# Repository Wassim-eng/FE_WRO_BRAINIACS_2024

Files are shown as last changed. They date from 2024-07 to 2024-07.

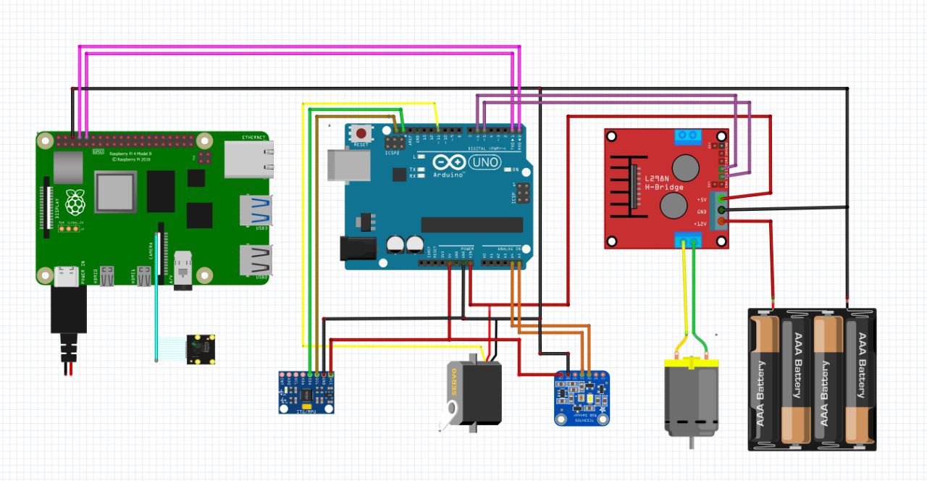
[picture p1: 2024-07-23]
schemes/Schematic_Diagram.jpeg

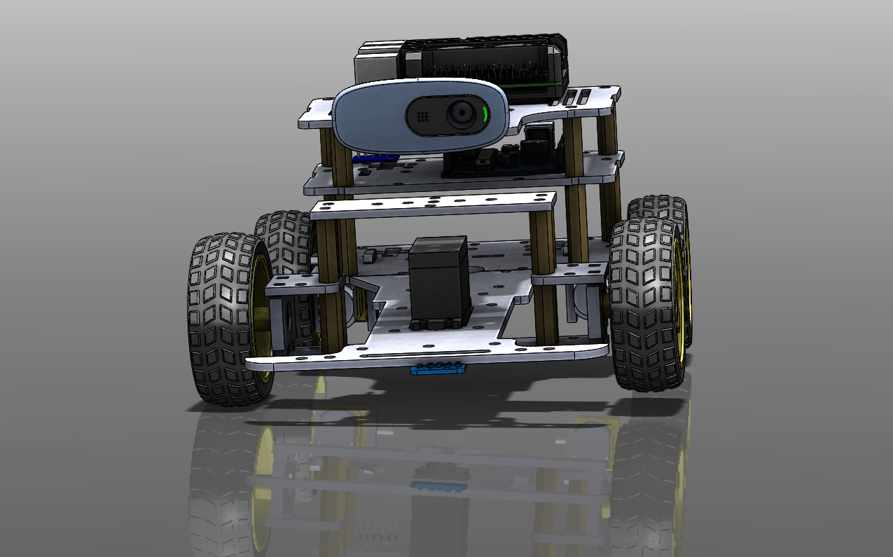
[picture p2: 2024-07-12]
Renders/Ren3.png

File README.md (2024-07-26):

# Content
- {CAD models} contains all the 3D modeled parts and assembly of the fully-autonomous driving vehicle
- {STL models} contains all the 3D printed parts of traffic signs,parking walls, clamps, covers, etc...
- {T-photos} contains 2 photos of the team (an official one and one funny photo with all team members)
- {V-photos} contains 6 photos of the vehicle (from every side, from top and bottom)
- {Video} contains the video.md file with the link to a video where driving demonstration exists
- {schemes} contains a schematic diagram in form of PNG of the electromechanical components illustrating all the elements (electronic components and motors) used in the vehicle and how they connect to each other.
- {src} contains code of control software for all components which were programmed to participate in the competition
- {models} is for the files for models used by 3D printers, laser cutting machines and CNC machines to produce the vehicle elements. If there is nothing to add to this location, the directory can be removed.
- {Project Report} contains the report that summarizes the teams work and describes the built prototype.

# Introduction  

In 35 days, Team Brainiacs has developed a self-driving autonomous car for the 2024 WRO future engineers’ competition. This car uses the principles of computer vision and PID to complete the specified rounds of this challenge. The car uses PID to control its movement and steering while using a color sensor to detect the corners of the playfield and turn accordingly. Moreover, computer vision was implemented using a Raspberry Pi 5 and a Logitech C270 camera a to detect the traffic signs and steer the car to complete the whole track.

The self-driving race car's code involves several key modules. A Raspberry Pi 5 runs computer vision algorithms to detect obstacles using camera data. Arduino Uno modules control the car's motors, servos, and sensors for movement and navigation. An MPU6050 gyroscope sensor ensures the car stays centered and stable while driving. Additionally, a TCS34725 color sensor detects environmental colors to aid in navigation and turning.

Our team’s work was based on the popular saying “ one hand can’t clap alone”. With the coach’s help and monitor the members could perfectly work by distributing work. Together Hassan and Mahmoud worked on the connection diagram and code writing. For processing the computer vision to detect the traffic signs, the coach was able to teach  the members how to be working in such an advanced level. As a result of this great work, the brainiacs team perfectly managed to perform a self-driving robot applicable with all rules provided for the competition.  

# Materials used:

•	Raspberry Pi 5 8GB Arduino UNO R3

•	GY-87 gyroscope

•	Adafruit TCS34725 color sensor

•	Logitech C270 720p30 webcam

•	1 High Speed DC motor

•	1 Mg995 geared servo motor

•	4x 4800mAh Lithium-Ion battery 18650 sticks

•	L298N Dual H-bridge Motor controller

•	Auxiliary 3D printed parts and laser cut chassis

•	Power bank 10000mAh

•	Switch module 

•	Tactile Push Button

•	LM2596S Step-down buck converter

# Programming Languages Used:

- Arduino C++
- Python

The code for the self-driving autonomous race robotic car consists of several modules that are related to the electromechanical components of the vehicle. The Raspberry Pi 5 module runs the computer vision algorithms that analyze camera data to detect obstacles in the car's path. The Arduino Uno module is responsible for controlling the motors, servos, and sensors that enable the car to move and navigate. The MPU6050 gyroscope sensor is used for PID control, which helps to maintain the car's stability and balance while driving. The TCS34725 color sensor detects colors in the environment, which can be used to help the car navigate.

To build and compile the code for the self-driving autonomous race robotic car, the Arduino IDE was used to program the Arduino boards using the C++ language. The Raspberry Pi 5 module used Linux-debian based operating system and the Python language to perform computer vision tasks. Manual compiling was done using the Linux command prompt on the Raspberry Pi. The code for the Arduino board was compiled into a binary file that could be uploaded to the boards using a USB cable or a wireless connection. The code for the Pi was written in Python and compiled manually using the Linux command prompt. Once the code was compiled, it could be uploaded to the controllers and executed to control the sensors and actuators and enable the car to drive autonomously. It is important to test the car in a safe environment and make adjustments to the code as needed to improve performance and reliability.

This self-driving car was established to be moving on a random lane according to the judges’ choice. The car must complete three rounds, an open round where it must complete 3 perfect turns on the lane chosen by the judge, the car during its turns would detect colored stripes on the 90 degree turn to either turn left (detecting orange color) where it moves clockwise or turn to the right (detecting blue color) where it moves in a counter clockwise motion. This challenge has a 3-minute max. time duration for the car to cover the whole 3 turns.

In the second challenge obstacles must be detected and avoided by the car. The car must detect traffic signs and avoid them. The self-driving car must pass the red pillar from the right and the green pillar from the left without moving or knocking down the obstacles outside the circular border drawn around them. 

The self-driving car must also perform a parallel parking in a lot 1.25 times the size of the car.   

The project by performing these challenges in a small scale and passing them in  a perfect manner could be performed in bigger scales to make all vehicles in the market as in our project. Develop an autonomous vehicle capable of navigating urban environments to perform all human purposes from transportation to delivery. Such an idea is performed using computer vision for obstacle detection using raspberry pi 5 and Arduino scripts to analyze and compute data to perform various stability and motion control through the different sensors, actuators, and devices.

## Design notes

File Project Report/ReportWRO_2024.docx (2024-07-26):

World Robotics Olympiad

Future Engineers Challenges

Self-driving Autonomous Car: Time attack and Obstacle Avoidance

Team Brainiacs

Coach: Wassim Ghaddar

Team members:

1) Hassan Harb
2) Mahmoud Mustapha

12/7/2024

Introduction

Team Brainiacs has developed a self-driving autonomous car for the 2024 WRO future engineers’ competition. This car uses the principles of computer vision and PID to complete the specified rounds of this challenge. The car uses PID to control its movement and steering while using a color sensor to detect the corners of the playfield and turn accordingly. Moreover, computer vision was implemented using a Raspberry PI 5 and raspberry Logitech C270 camera to detect the traffic signs and steer the car to complete the whole track.

The self-driving race car's code involves several key modules. A Raspberry Pi 5 runs computer vision algorithms to detect obstacles using camera data. Arduino Uno modules control the car's motors, servos, and sensors for movement and navigation. An MPU6050 gyroscope sensor ensures the car stays centered and stable while driving. Additionally, a TCS34725 color sensor detects environmental colors to aid in navigation and turning.

Our team’s work was based on the popular saying “ one hand can’t clap alone”. With the coach’s help and monitor the members could perfectly work by distributing work. Together Hassan and Mahmoud worked on the connection diagram and code writing. For processing the computer vision to detect the traffic signs, the coach was able to teach the members how to be working in such an advanced level. As a result of this great work, the brainiacs team perfectly managed to perform a self-driving robot applicable with all rules provided for the competition.

Project Idea

This self-driving car was established to be moving on a random lane according to the judges’ choice. The car must complete three rounds, an open round where it must complete 3 perfect turns on the lane chosen by the judge, the car during its turns would detect colored stripes on the 90 degree turn to either turn left (detecting orange color) where it moves clockwise or turn to the right (detecting blue color) where it moves in a counter clockwise motion. This challenge has a 3-minute max. time duration for the car to cover the whole 3 turns.

In the second challenge obstacles must be detected and avoided by the car. The car must detect traffic signs and avoid them. The self-driving car must pass the red pillar from the right and the green pillar from the left without moving or knocking down the obstacles outside the circular border drawn around them.

The self-driving car must also perform a parallel parking in a lot 1.25 times the size of the car.

The project by performing these challenges in a small scale and passing them in a perfect manner could be performed in bigger scales to make all vehicles in the market as in our project. Develop an autonomous vehicle capable of navigating urban environments to perform all human purposes from transportation to delivery. Such an idea is performed using computer vision for obstacle detection using raspberry pi 5 and Arduino scripts to analyze and compute data to perform various stability and motion control through the different sensors, actuators, and devices.

Robotic Solution

Materials used:

- Raspberry Pi 5 8gb
- Arduino UNO R3
- GY-87 gyroscope
- Adafruit TCS34725 color sensor
- Logitech C270 720p30 webcam
- 1 High Speed DC motor
- 1 Mg995 geared servo motor
- 4x 4800mAh Lithium-Ion battery 18650 sticks
- L298N Dual H-bridge Motor controller
- Auxiliary 3D printed parts and laser cut chassis
- Power bank 10000mAh
- Switch module
- Tactile Push Button
- LM2596S Step-down buck converter

Programming Languages Used

- Arduino C++
- Python


Schematic Diagrams

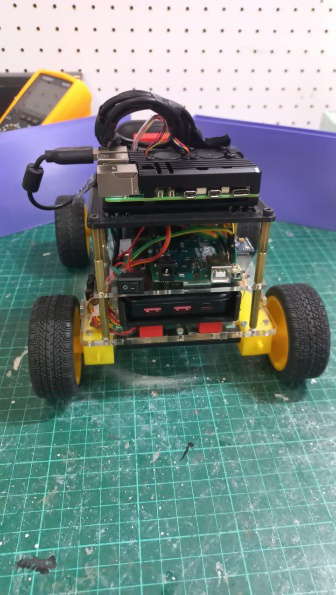
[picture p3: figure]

Pictures of The Robot

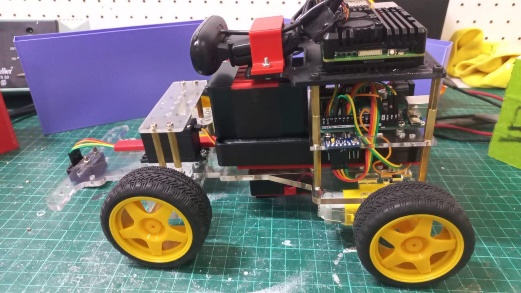
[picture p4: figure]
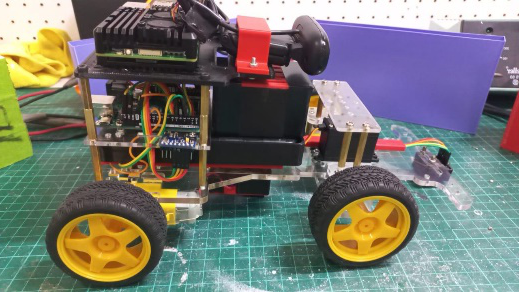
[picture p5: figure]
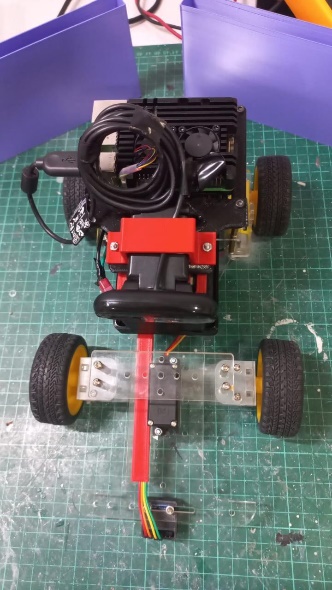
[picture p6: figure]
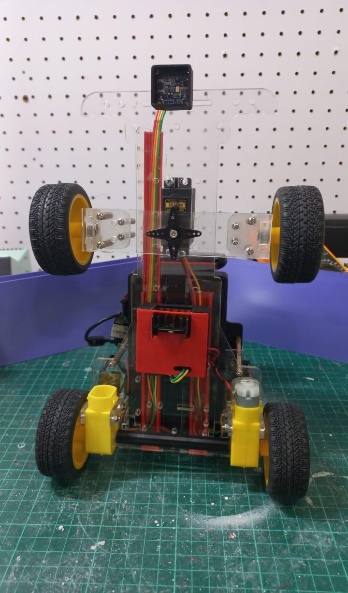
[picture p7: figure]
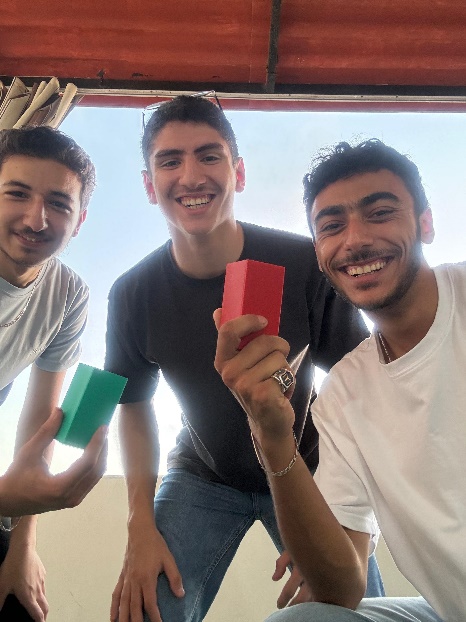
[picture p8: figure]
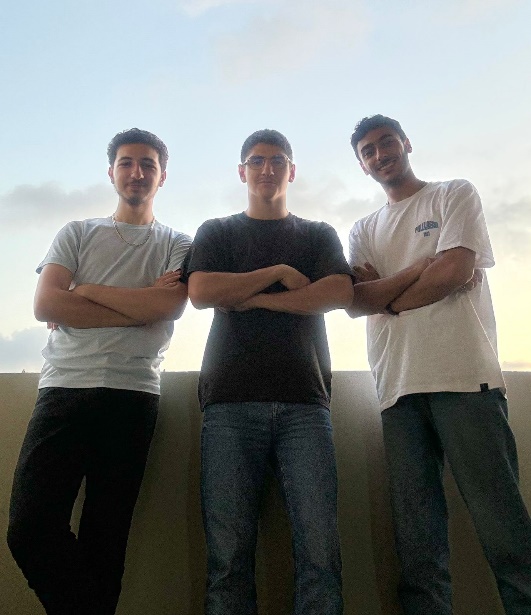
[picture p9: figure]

Team Pictures

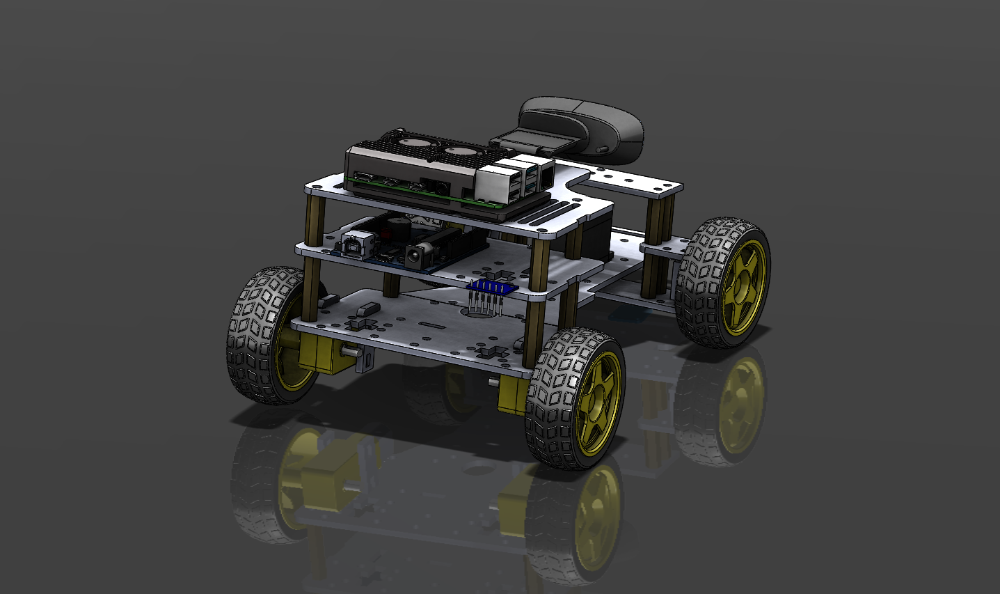
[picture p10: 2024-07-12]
Renders/Ren2.png

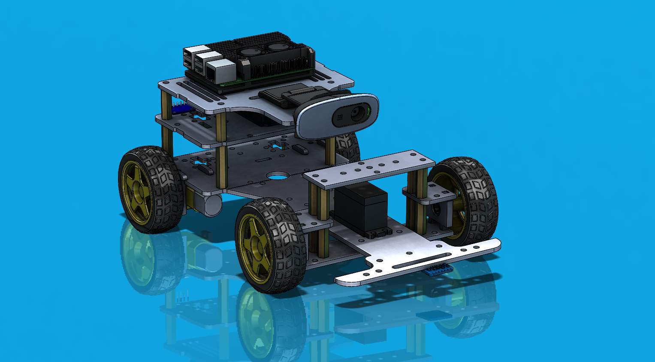
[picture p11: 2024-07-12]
Renders/Ren5.png

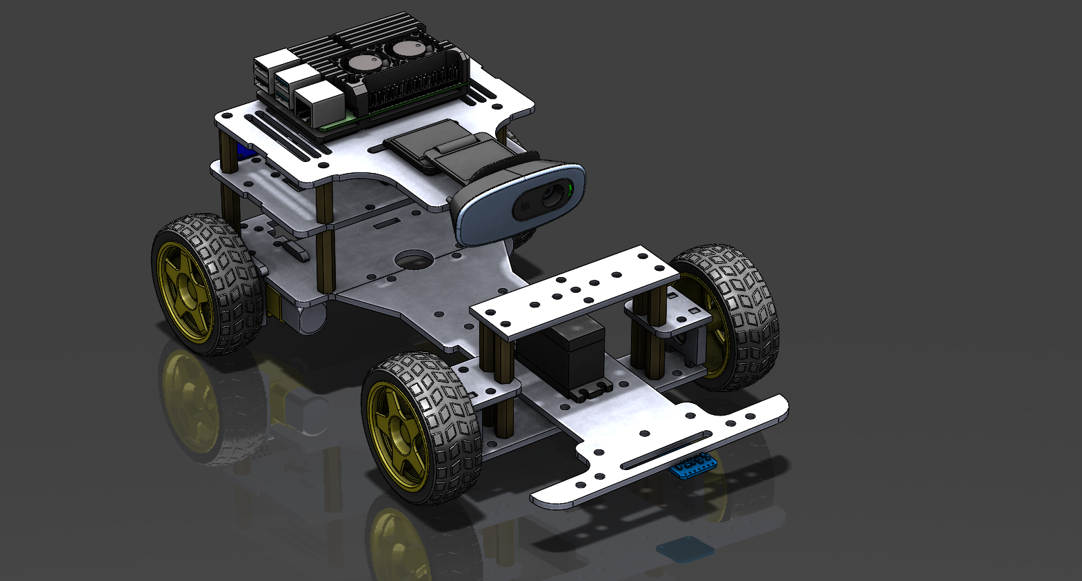
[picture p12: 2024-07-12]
Renders/Ren4.png

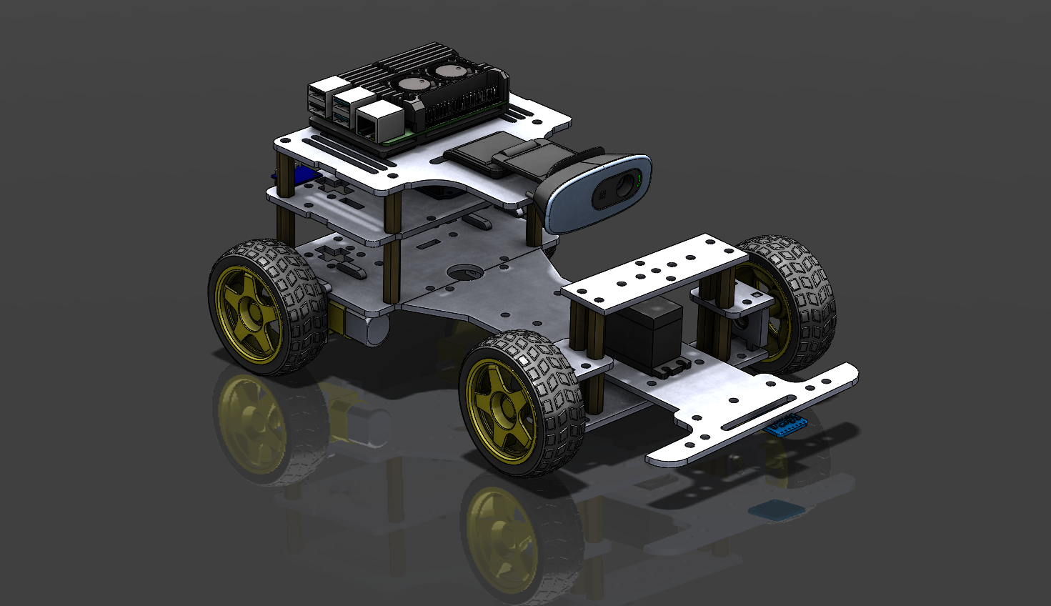
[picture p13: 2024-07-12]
Renders/Ren1.png

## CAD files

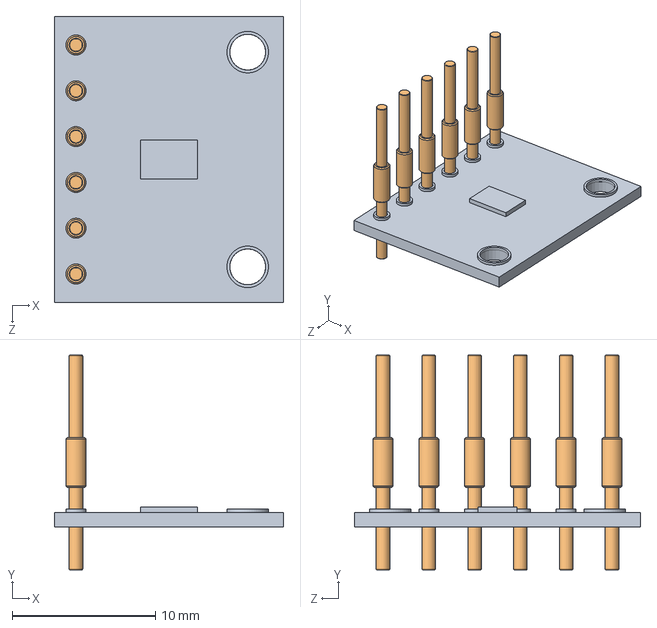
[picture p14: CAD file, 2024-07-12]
CAD models/Gyrosensor.SLDASM
16.0 x 15.0 x 20.0 mm
Gyroscope sensor
Gyroscope sensor straight lead x 6

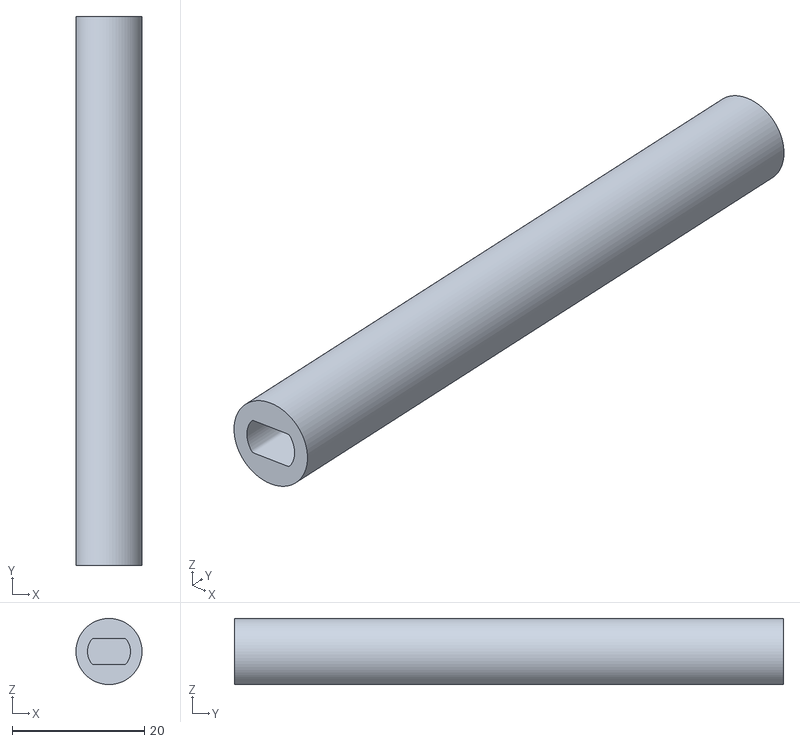
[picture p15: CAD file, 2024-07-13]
STL models/axle.STL
10.0 x 83.0 x 10.0

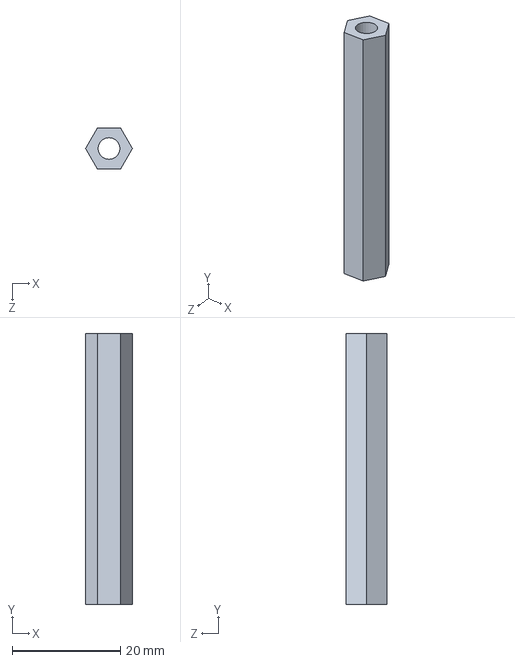
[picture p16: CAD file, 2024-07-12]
CAD models/standoff_short.SLDPRT
8.66 x 50.0 x 7.50 mm

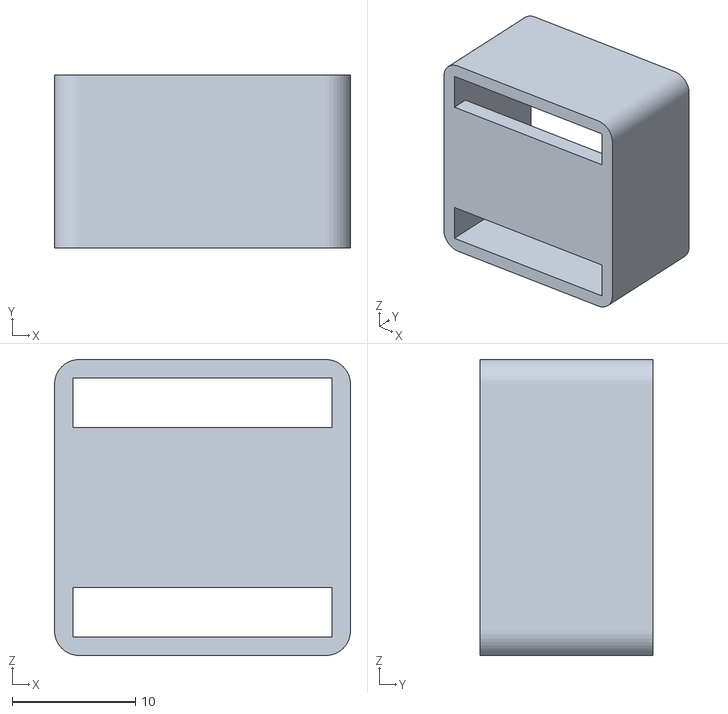
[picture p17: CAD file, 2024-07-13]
STL models/Color_Sens_cover.STL
24.0 x 14.0 x 24.0

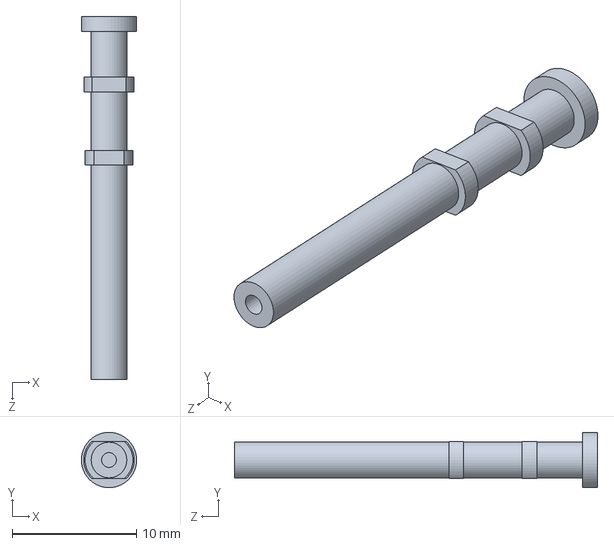
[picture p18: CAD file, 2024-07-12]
CAD models/Pin camera Mtg Plastic Logi c270.SLDPRT
4.45 x 4.44 x 29.2 mm

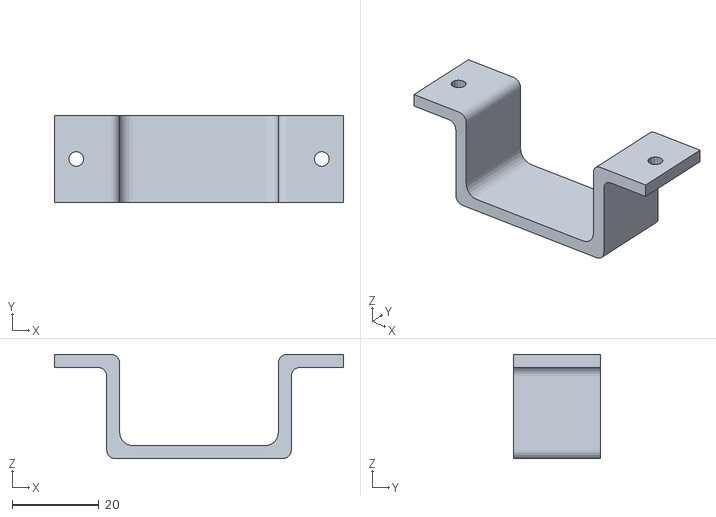
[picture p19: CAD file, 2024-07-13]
STL models/clamp.STL
66.5 x 20.0 x 24.0

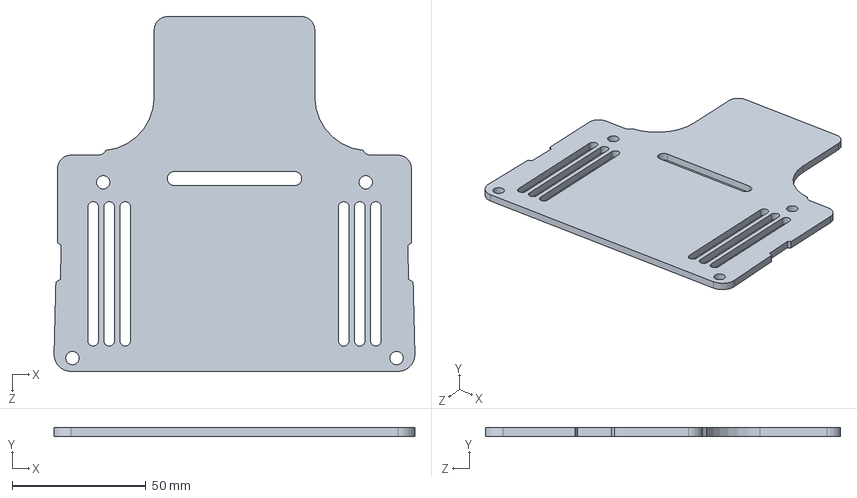
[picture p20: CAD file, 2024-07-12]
CAD models/piandweb_mounts.SLDPRT
134.8 x 3.17 x 132.5 mm

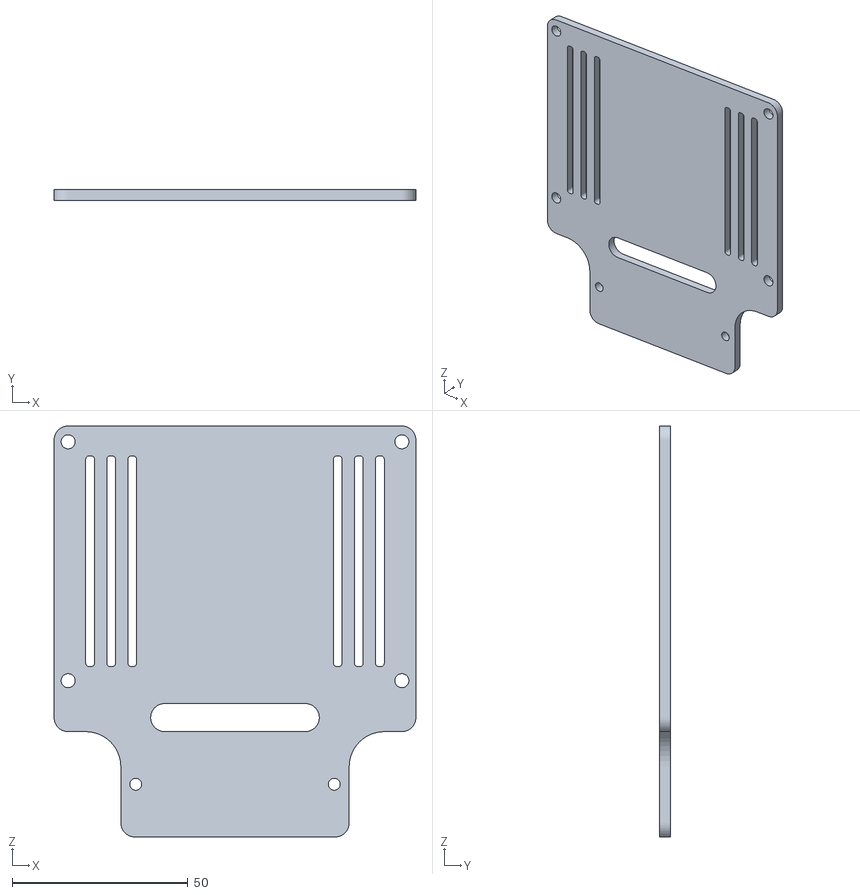
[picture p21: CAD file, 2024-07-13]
STL models/base_v1.STL
103.0 x 3.00 x 117.0

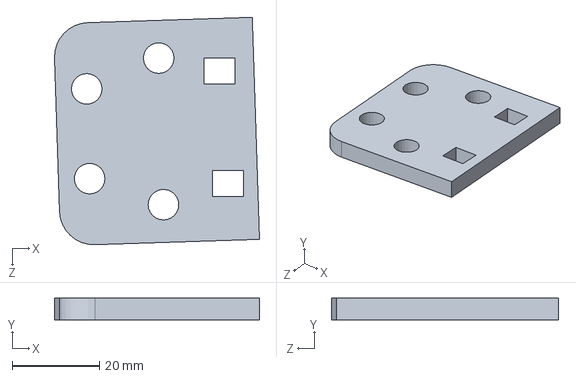
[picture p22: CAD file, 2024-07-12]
CAD models/Boss-Extrude4.SLDPRT
46.9 x 5.00 x 52.0 mm

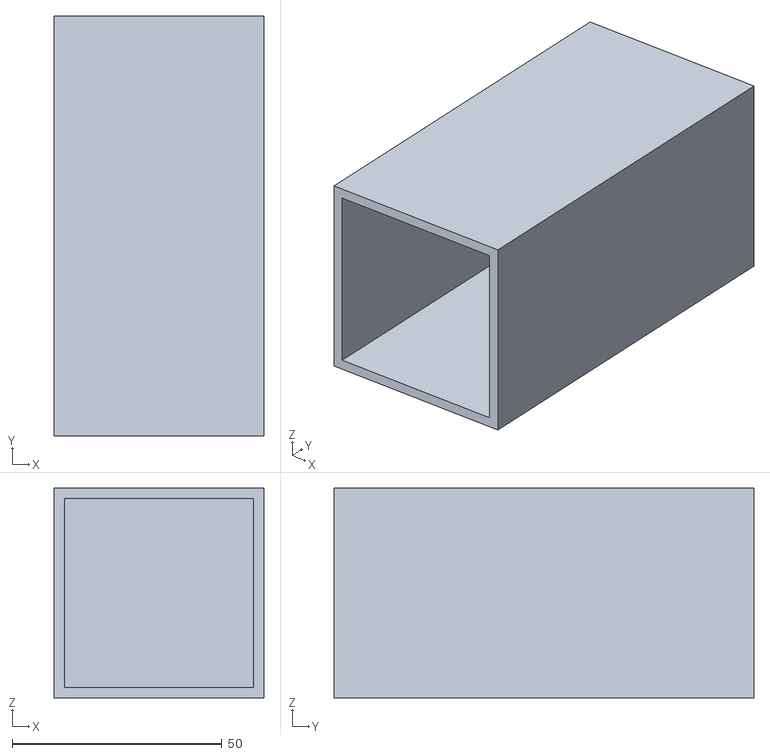
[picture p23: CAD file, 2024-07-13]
STL models/traffic sign.STL
50.0 x 100.0 x 50.0

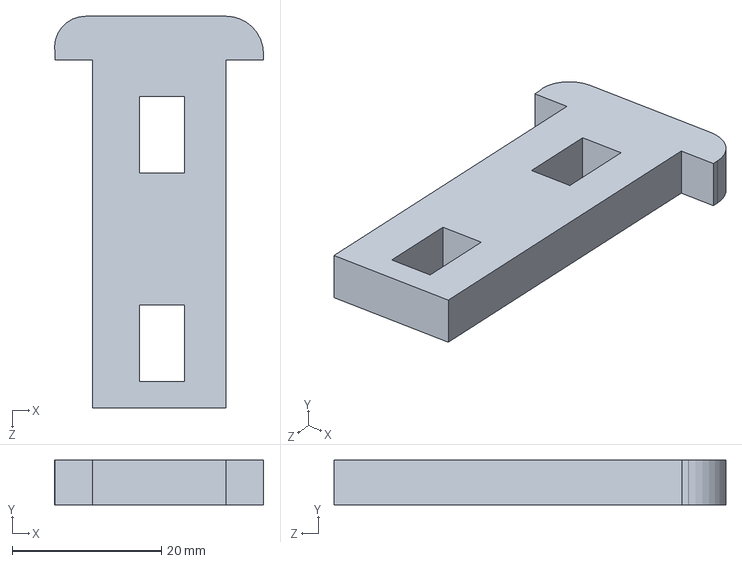
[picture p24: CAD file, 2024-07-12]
CAD models/Boss-Extrude6.SLDPRT
28.0 x 6.00 x 52.5 mm

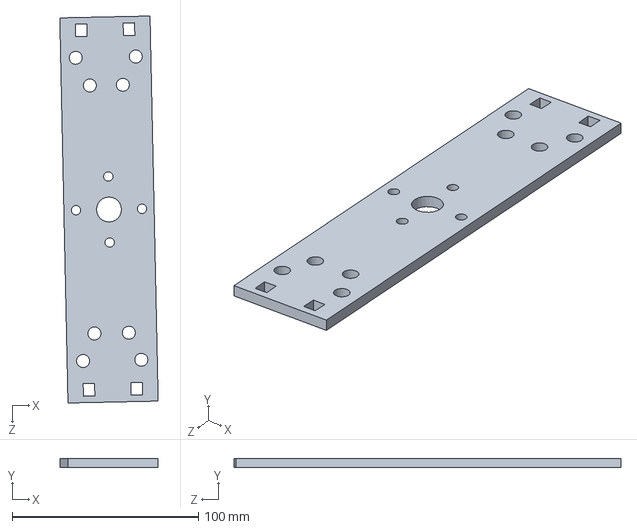
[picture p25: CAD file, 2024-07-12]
CAD models/Boss-Extrude2.SLDPRT
52.8 x 5.00 x 207.8 mm

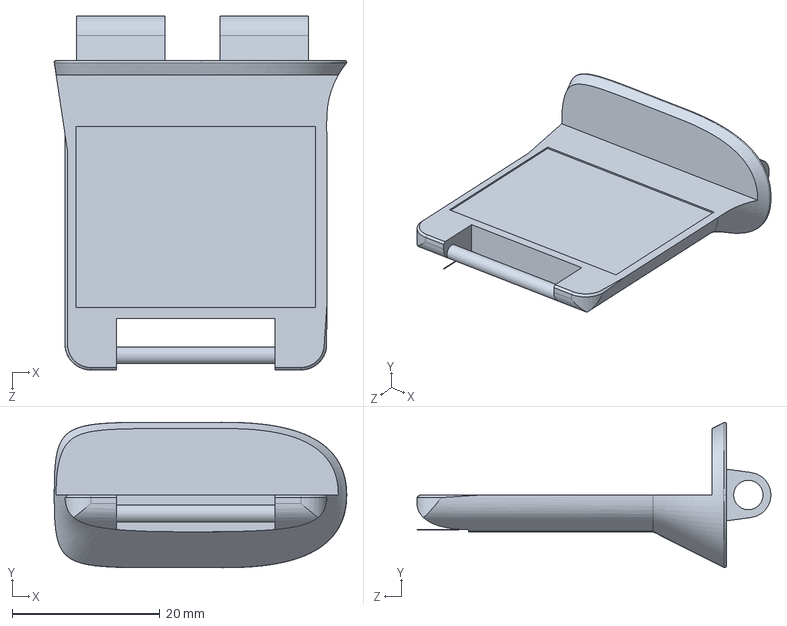
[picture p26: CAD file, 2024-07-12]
CAD models/Logitech c270b.SLDPRT
39.7 x 19.7 x 48.0 mm

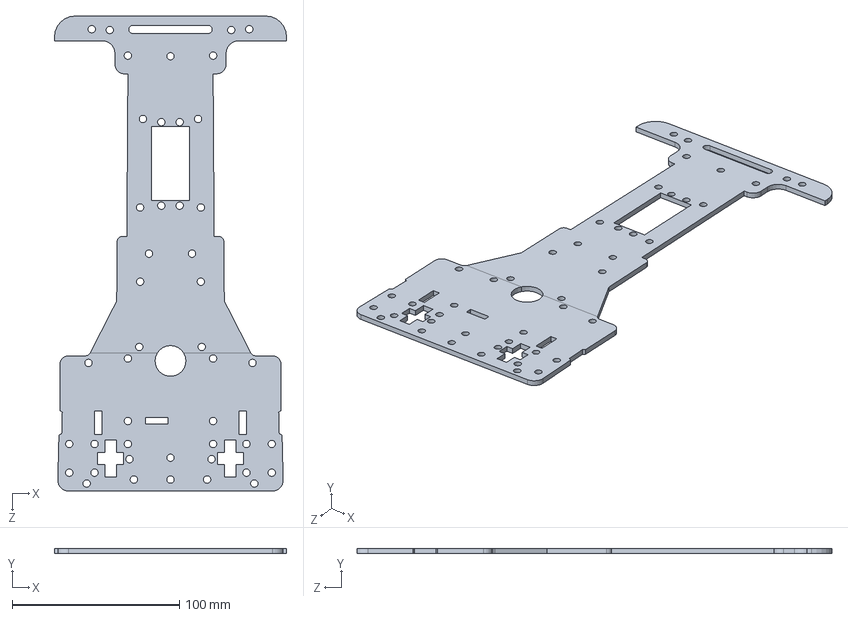
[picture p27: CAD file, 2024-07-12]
CAD models/Cut-Extrude2.SLDPRT
138.7 x 3.17 x 284.0 mm

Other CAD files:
CAD models/Logitech c270 Assembly.SLDASM
CAD models/standoff_tall.SLDPRT
CAD models/Mg995.SLDPRT
CAD models/Boss-Extrude3.SLDPRT
CAD models/Boss-Extrude5.SLDPRT
CAD models/Logitech c270.SLDPRT
CAD models/Logitech c270c.SLDPRT
CAD models/Servo_MG995_Star_horn.SLDPRT
CAD models/Split1[1].SLDPRT
CAD models/Wheel D65x25.SLDPRT
CAD models/tcs34725.sldprt

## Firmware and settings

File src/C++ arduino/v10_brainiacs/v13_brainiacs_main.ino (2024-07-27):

#include <Wire.h>
#include <MPU6050_tockn.h>
#include <Servo.h>
#include <Adafruit_TCS34725.h>

// Initialize MPU6050 and servo
MPU6050 mpu6050(Wire);
Servo myservo;

// Color sensor instance
Adafruit_TCS34725 tcs = Adafruit_TCS34725(TCS34725_INTEGRATIONTIME_24MS, TCS34725_GAIN_16X);

// PID constants
double Kp = 1.3;   // Proportional gain
double Ki = 0;     // Integral gain
double Kd = 0.5;   // Derivative gain

// Variables for PID control
long error = 0;
long lastError = 0;
long de;
long Pr;
int sum = 0;
long integral = 0;

// Target angle
int setpoint = 0;

// Deadband range
const int deadband = 0.5;  // Example deadband range

// Target angle for lane correction
int waypoint = -165;

// Counter for lane corrections
int count = 1;

// Center position for the servo
const int servo_center = 92;

// Motor speed
const int Motor_Speed = 80;

// Servo movement limits
const int servo_min = 60;
const int servo_max = 120;

void setup() {
  Serial.begin(9600);

  // Initialize MPU6050 and servo
  Wire.begin();
  mpu6050.begin();
  mpu6050.calcGyroOffsets(true);

  // Attach servo to pin 11
  myservo.attach(11);

  // Initialize color sensor
  if (tcs.begin()) {
    Serial.println("Color sensor found");
  } else {
    Serial.println("Color sensor not found. Check wiring.");
    while (1);  // Halt if sensor not found
  }
  mpu6050.update();
  setpoint = mpu6050.getAngleZ();
}

void loop() {
  if (count<=12){
  // Start with forward motion
  analogWrite(5, Motor_Speed);  // Assuming pin A for motor control

  // Update MPU6050 data
  mpu6050.update();
  error = mpu6050.getAngleZ();

  // PID control with deadband
  error = setpoint - error;
  
 

  Pr = error;
  de = error - lastError;
  lastError = error;
  // Update lastError for next iteration
  integral = integral + error;
  sum = Ki * integral + Kp * Pr + Kd * de;
  // Adjust servo based on PID output and constrain the final position
  int servo_position = constrain(-sum + servo_center, servo_min, servo_max);
  myservo.write(servo_position);

  // Read color sensor
  uint16_t r, g, b, c;
  tcs.getRawData(&r, &g, &b, &c);
  float sum_rgb = r + g + b;
  float r_ratio = r / sum_rgb;
  float g_ratio = g / sum_rgb;
  float b_ratio = b / sum_rgb;

  // Color detection and setpoint adjustment for orange color
  if (r_ratio > 0.35 && g_ratio > 0.25 && b_ratio < 0.32) {
    int juwa = 0;
    while (juwa >= waypoint * count) {
      mpu6050.update();
      juwa = mpu6050.getAngleZ();
      // Adjust servo to correct towards right
      myservo.write(constrain(servo_center + 29, servo_min, servo_max));
    }
  
    count++;
    setpoint = juwa;
    myservo.write(servo_center);
  
  }
  
    // Color detection and setpoint adjustment for blue color
    if (b_ratio > 0.35 && r_ratio < 0.32 && g_ratio < 0.35){
        int juwa = 0;
        while (juwa <= -waypoint * count) {
            mpu6050.update();
            juwa = mpu6050.getAngleZ();
            // Adjust servo to correct towards left
          myservo.write(constrain(servo_center - 29, servo_min, servo_max));
   }
    count++;
    setpoint = juwa;
    myservo.write(servo_center);
   }
  }
  else{
  analogWrite(5, 0);  // Assuming pin A for motor control
  
  }
}

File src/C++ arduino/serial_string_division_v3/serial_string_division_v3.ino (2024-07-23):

int intValue;
char charValue;
float distance;

void setup() {
  Serial.begin(115200);

  while (!Serial) {
    ;
  }

  Serial.println("Arduino is ready");
}

void loop() {
  if (Serial.available() > 0) {
    String receivedString = Serial.readStringUntil('\n');  // Read until a newline character is introduced

    if (receivedString.length() > 0) {
      receivedString.trim();  // Trim whitespace at the end of the line
      // Check if the received string contains a comma as pi 5 parses the serial messages as(color_index_char[0],int[np.degrees(horizontal_angle)], distance_mm)
      int commaIndex = receivedString.indexOf(',');
      if (commaIndex != -1) {  //if there is not index of a comma at all no execution will occur thus this value would be addressed as garbage data (filtering)
        // Extract the substring before the comma (potential color or angle)
        String beforeComma = receivedString.substring(0, commaIndex);

        // Check if it starts with 'g' or 'r' to determine color
        if (beforeComma.startsWith("g") || beforeComma.startsWith("r")) {
          charValue = beforeComma.charAt(0);  // Get the color character ('g' or 'r')

          // Extract the angle part as a substring after the color
          String anglePart = beforeComma.substring(1);  // Skip the color character
          intValue = anglePart.toInt();                 // Convert angle part to integer
        }

        // Extract distance part after the comma
        String distancePart = receivedString.substring(commaIndex + 1);  // Get substring after comma
        distance = distancePart.toFloat();                               // Convert distance part to float

        // Print received data for debugging
        Serial.print("Received - Color: ");
        Serial.print(charValue);
        Serial.print(", Angle: ");
        Serial.print(intValue);
        Serial.print(", Distance: ");
        Serial.println(distance);

        switch (charValue) {
          case 'g':
            if (distance > 200) {
              Serial.print("GREEN detected and distance is more than 200 by: ");
              Serial.println(distance - 200);
              // Example: Move Towards it (adjust until angle recieved = 0) call a function for adjustment
              CNTR_ANG(intValue);

            } else {
              Serial.println("GREEN detected and distance is less than 200mm.");
              Serial.println("Turn inside immediately.");
              // Example: Turn Servo Inside
              Green_maneuver(intValue);
            }
            break;

          case 'r':
            if (distance > 200) {
              Serial.print("RED detected and distance is more than 200 by: ");
              Serial.println(distance - 200);
              // Example: Move Towards it (adjust until angle recieved = 0) call a function for adjustment
              CNTR_ANG(intValue);
            } else {
              Serial.println("RED detected and distance is less than 200mm.");
              Serial.println("Turn inside immediately.");
              Red_maneuver(intValue);
              // Example: Turn Servo Outside
            }
            break;

          default:
            Serial.println("Unknown color detected.");
            // Handle case where an unknown color is received
            break;
        }
      }
    }
  }
  
}


void CNTR_ANG(int value) {
  if (intValue != 0) {
    //myservo.write(servo_center + intValue)
  } else {
    Serial.print("CENTERRRRRRRRRRRRRRRRRRRRREEEEEEEEEEEEEEEEEEEED");
  }
}
void Green_maneuver(int value) {
}
void Red_maneuver(int value) {
}

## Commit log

2024-07-12 Second Commit
    [Boss-Extrude2.SLDPRT, Boss-Extrude3.SLDPRT, Boss-Extrude4.SLDPRT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]
2024-07-13 Models STL Ccmmit
    [Color_Sens_cover.STL, base_v1.STL, clamp.STL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]
2024-07-23 Update in arduino script
    Contains: fine color adjustments and multiple gyro setpoint adjustments
2024-07-23 Update over some details to be able to properly send the data to arduino in a string form
    string form used example: "g-27,200" which later gets computed in the Arduino for further maneuver planning
2024-07-23 Report,Photos,Schematic Diagram
